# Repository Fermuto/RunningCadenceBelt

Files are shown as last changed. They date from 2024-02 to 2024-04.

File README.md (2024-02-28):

# RunningCadenceBelt

Running cadence is the number of steps a runner takes per minute while running, commonly measured in strides per minute (SPM). It is a useful measurement for runners as it can provide insight into efficiency, form, and stride length. An ideal cadence for most runners typically falls into the range of 170 to 180 SPM although this is dependent on height and pace.

Currently, there are already products on the market that can measure running cadence. For example, most “running watches” have cadence as an included measurement. However, it can be cumbersome for runners to constantly switch through display screens to monitor multiple data points at the same time such as pace, heart rate, distance, and cadence. Furthermore, unless a runner is running with their arm locked in front of them, continuous monitoring of cadence is impossible with a running watch. Other products take a different approach such as the foot-mounted ARION Footpod non-GPS 1.0 and Stryd. These products can track the cadence throughout the run in much the same way that a running watch would, but they can’t provide that information to the runner without the use of a watch or smartphone. In both the watch and foot-mounted solution, there is a lack of a product that provides easy, hands-free haptic feedback to the runner informing them when their cadence falls outside of the ideal cadence range.

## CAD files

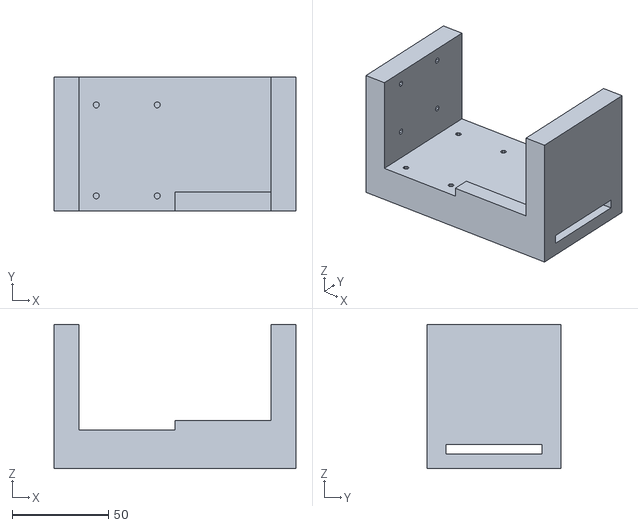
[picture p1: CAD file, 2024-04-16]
3D Print/Print.stl
126.0 x 70.0 x 75.0

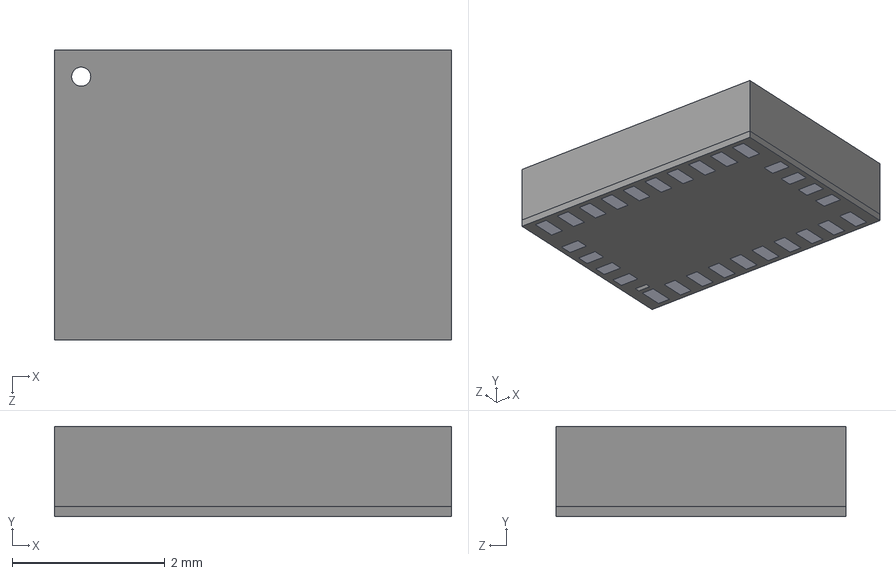
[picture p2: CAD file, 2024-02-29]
PCB/footprints/BNO085/BNO085.step
5.20 x 1.18 x 3.80 mm

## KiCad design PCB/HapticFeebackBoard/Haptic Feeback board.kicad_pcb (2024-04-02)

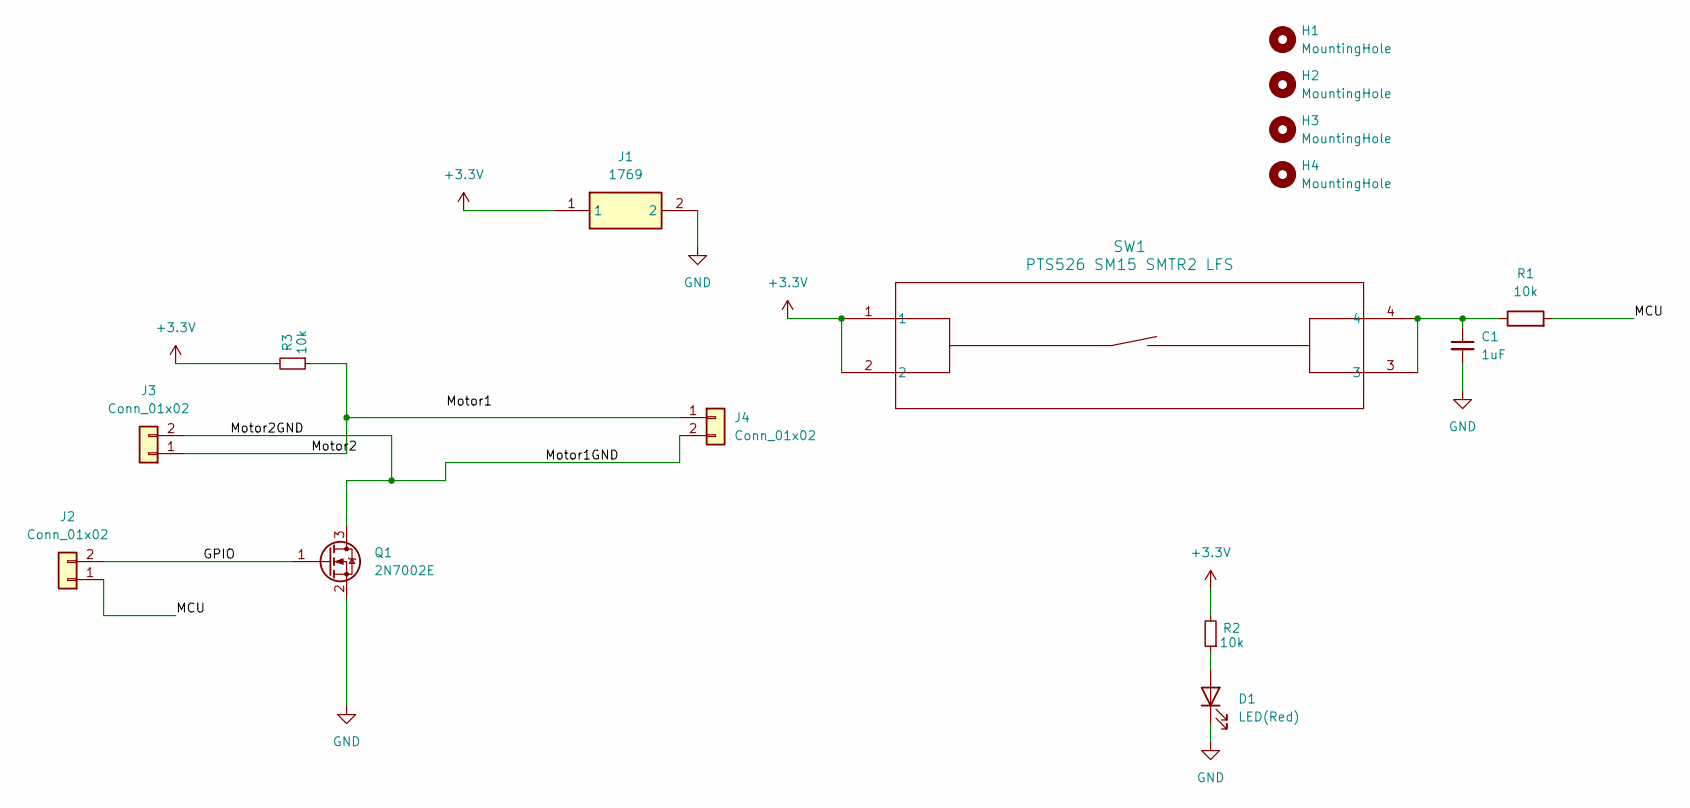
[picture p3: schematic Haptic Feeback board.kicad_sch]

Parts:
C1: 1uF; C_0805_2012Metric_Pad1.18x1.45mm_HandSolder
D1: LED(Red); LED_0603_1608Metric_Pad1.05x0.95mm_HandSolder
H1, H2, H3, H4: MountingHole; MountingHole_3.2mm_M3
J1: 1769; Mouser Part Number 485-1769
J2, J3, J4: Conn_01x02; Molex_KK-254_AE-6410-02A_1x02_P2.54mm_Vertical
Q1: 2N7002E; SOT-23-3
R1, R2, R3: 10k; R_0805_2012Metric_Pad1.20x1.40mm_HandSolder
SW1: PTS526 SM15 SMTR2 LFS; SON4_PTS526 SM15 SMTR2 LFS_CNK

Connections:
+3.3V: J1.1, R2.2, R3.2, SW1.1, SW1.2
/GPIO: J2.2, Q1.1 (G)
/MCU: J2.1, R1.2
/Motor1GND: J3.2, J4.2, Q1.3 (D)
/Motor2: J3.1, J4.1, R3.1
GND: C1.2, D1.1 (K), J1.2, Q1.2 (S)
unnamed: C1.1, R1.1, SW1.3, SW1.4
unnamed: D1.2 (A), R2.1

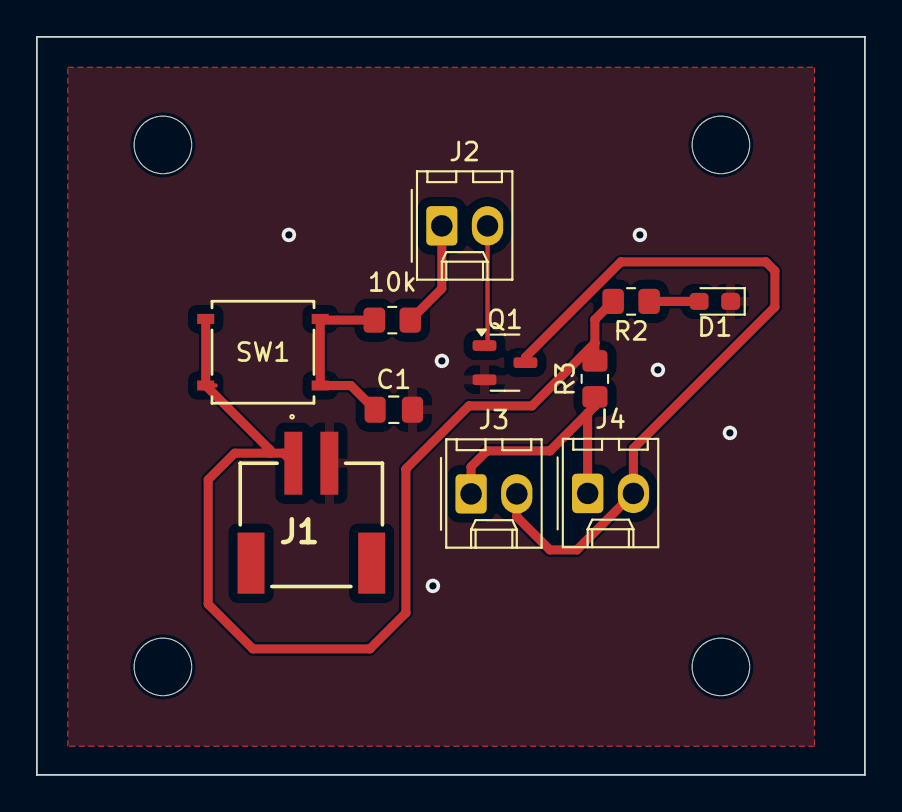
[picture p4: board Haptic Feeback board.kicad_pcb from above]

Board: 2 copper layers, 46.0 x 41.0 mm, 15 parts (0 on the bottom side), 8 nets.

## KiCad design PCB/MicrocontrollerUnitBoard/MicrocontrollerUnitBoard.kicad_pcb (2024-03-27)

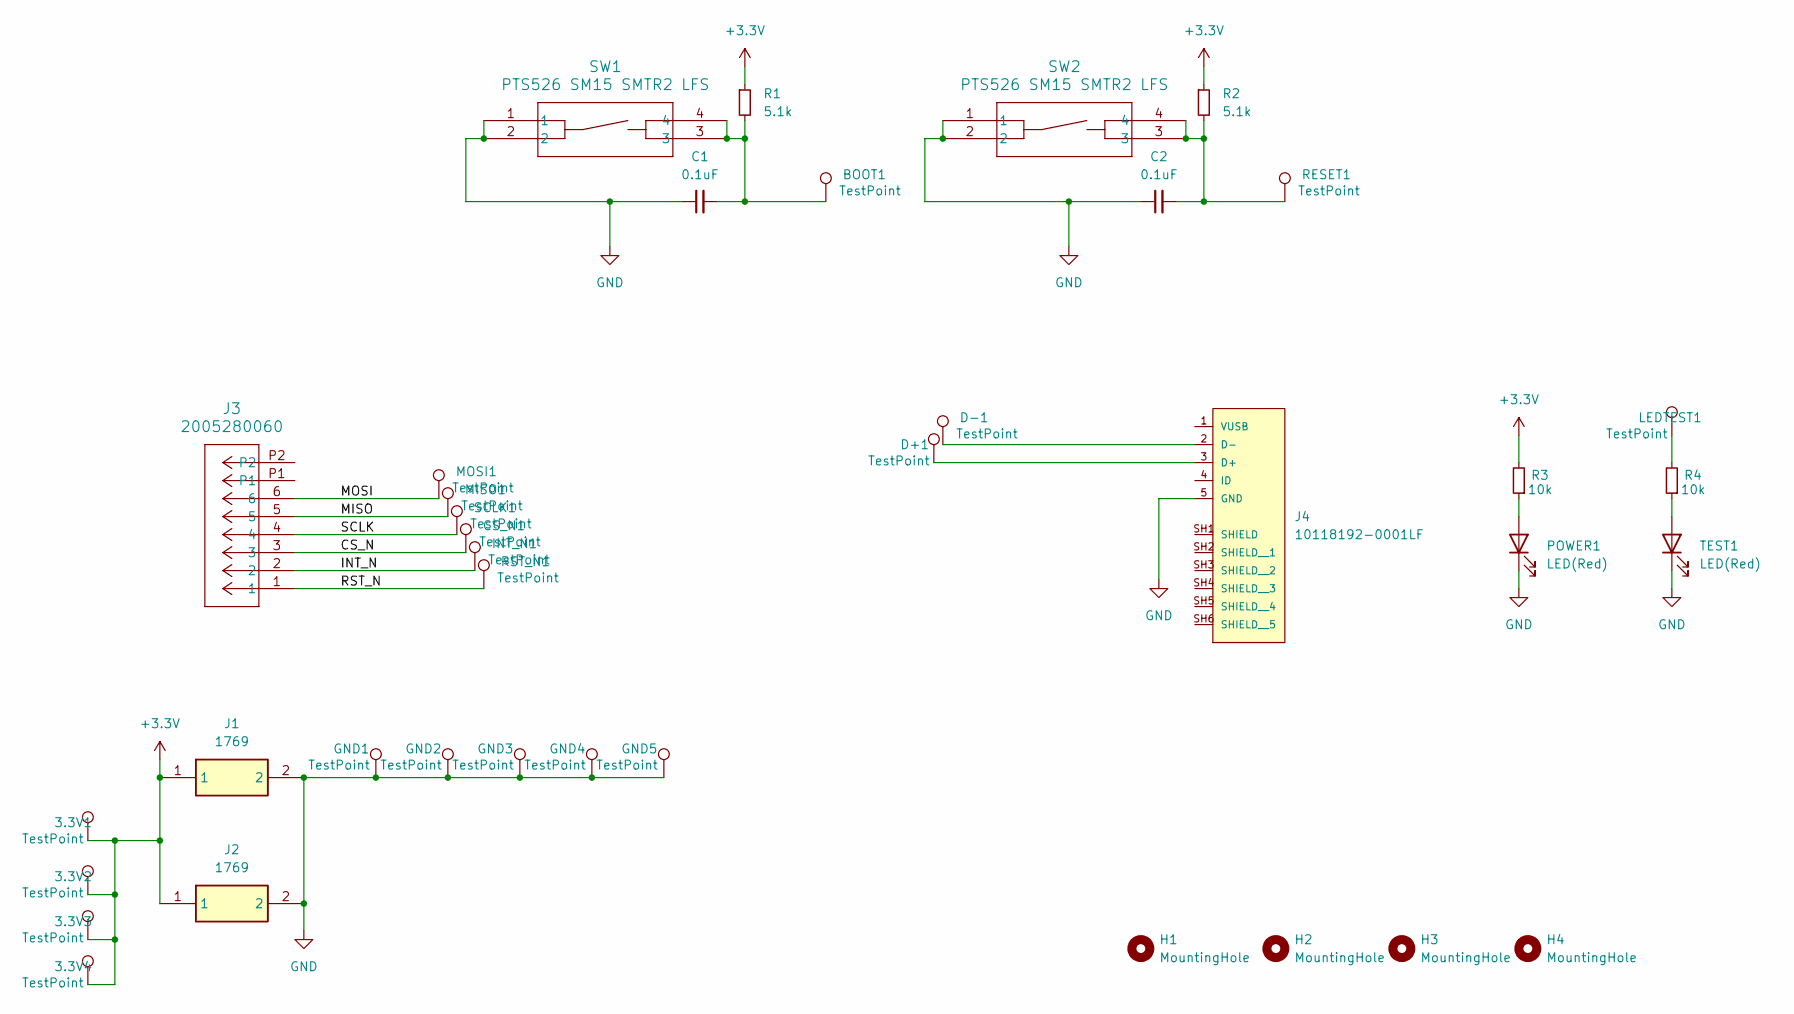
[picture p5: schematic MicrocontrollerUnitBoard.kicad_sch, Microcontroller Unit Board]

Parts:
3.3V1, 3.3V2, 3.3V3, 3.3V4: TestPoint; TestPoint_THTPad_D2.0mm_Drill1.0mm
BOOT1: TestPoint; TestPoint_THTPad_D2.0mm_Drill1.0mm
C1, C2: 0.1uF; C_0805_2012Metric_Pad1.18x1.45mm_HandSolder
CS_N1: TestPoint; TestPoint_THTPad_D2.0mm_Drill1.0mm
D+1: TestPoint; TestPoint_THTPad_D2.0mm_Drill1.0mm
D-1: TestPoint; TestPoint_THTPad_D2.0mm_Drill1.0mm
GND1, GND2, GND3, GND4, GND5: TestPoint; TestPoint_THTPad_D2.0mm_Drill1.0mm
H1, H2, H3, H4: MountingHole; MountingHole_3.2mm_M3
INT_N1: TestPoint; TestPoint_THTPad_D2.0mm_Drill1.0mm
J1, J2: 1769; Mouser Part Number 485-1769
J3: 2005280060; CON_2005280060_MOL
J4: 10118192-0001LF; AMPHENOL_10118192-0001LF; PARTREV B
LEDTEST1: TestPoint; TestPoint_THTPad_D2.0mm_Drill1.0mm
MISO1: TestPoint; TestPoint_THTPad_D2.0mm_Drill1.0mm
MOSI1: TestPoint; TestPoint_THTPad_D2.0mm_Drill1.0mm
POWER1: LED(Red); LED_0603_1608Metric_Pad1.05x0.95mm_HandSolder
R1, R2: 5.1k; R_0805_2012Metric_Pad1.20x1.40mm_HandSolder
R3, R4: 10k; R_0805_2012Metric_Pad1.20x1.40mm_HandSolder
RESET1: TestPoint; TestPoint_THTPad_D2.0mm_Drill1.0mm
RST_N1: TestPoint; TestPoint_THTPad_D2.0mm_Drill1.0mm
SCLK1: TestPoint; TestPoint_THTPad_D2.0mm_Drill1.0mm
SW1, SW2: PTS526 SM15 SMTR2 LFS; SON4_PTS526 SM15 SMTR2 LFS_CNK
TEST1: LED(Red); LED_0603_1608Metric_Pad1.05x0.95mm_HandSolder

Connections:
+3.3V: 3.3V1.1, 3.3V2.1, 3.3V3.1, 3.3V4.1, J1.1, J2.1, R1.1, R2.1, R3.2
/CS_N: CS_N1.1, J3.3
/INT_N: INT_N1.1, J3.2
/MISO: J3.5, MISO1.1
/MOSI: J3.6, MOSI1.1
/RST_N: J3.1, RST_N1.1
/SCLK: J3.4, SCLK1.1
GND: C1.1, C2.1, GND1.1, GND2.1, GND3.1, GND4.1, GND5.1, J1.2, J2.2, J4.5 (GND), POWER1.1 (K), SW1.1, SW1.2, SW2.1, SW2.2, TEST1.1 (K)
unnamed: BOOT1.1, C1.2, R1.2, SW1.3, SW1.4
unnamed: C2.2, R2.2, RESET1.1, SW2.3, SW2.4
unnamed: D+1.1, J4.3 (D+)
unnamed: D-1.1, J4.2 (D-)
unnamed: LEDTEST1.1, R4.2
unnamed: POWER1.2 (A), R3.1
unnamed: R4.1, TEST1.2 (A)

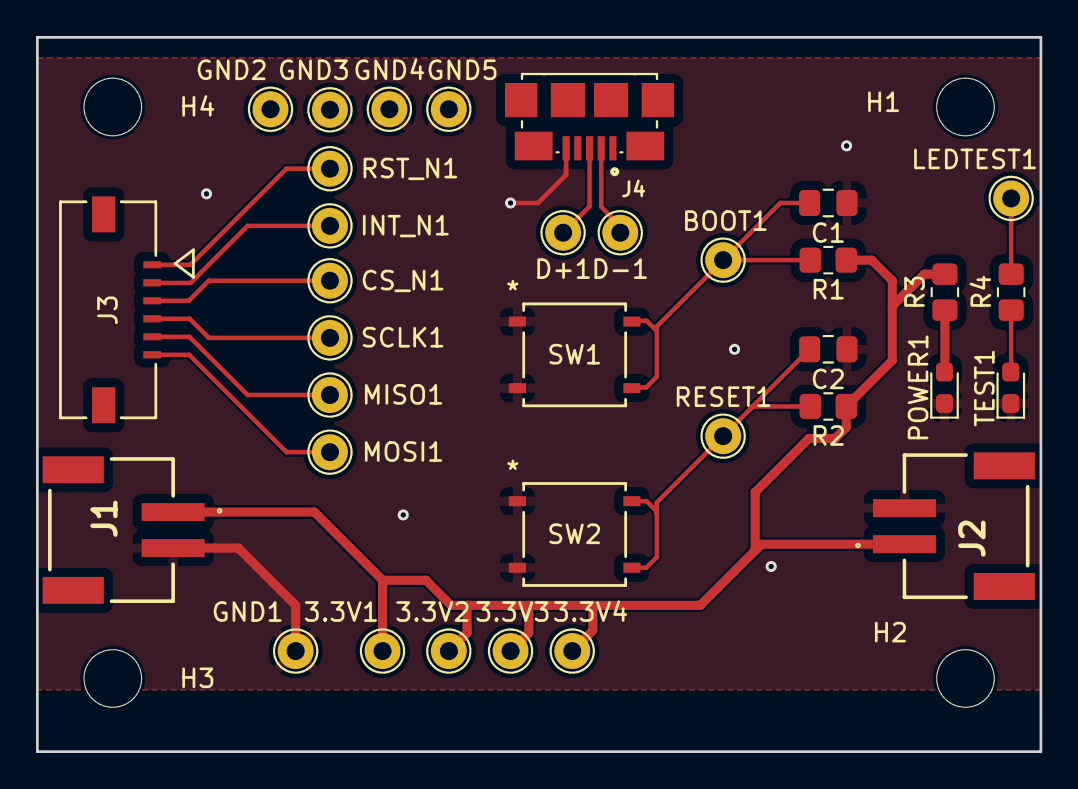
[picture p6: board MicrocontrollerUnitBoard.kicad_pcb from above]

Board: 2 copper layers, 55.8 x 39.7 mm, 38 parts (0 on the bottom side), 15 nets.

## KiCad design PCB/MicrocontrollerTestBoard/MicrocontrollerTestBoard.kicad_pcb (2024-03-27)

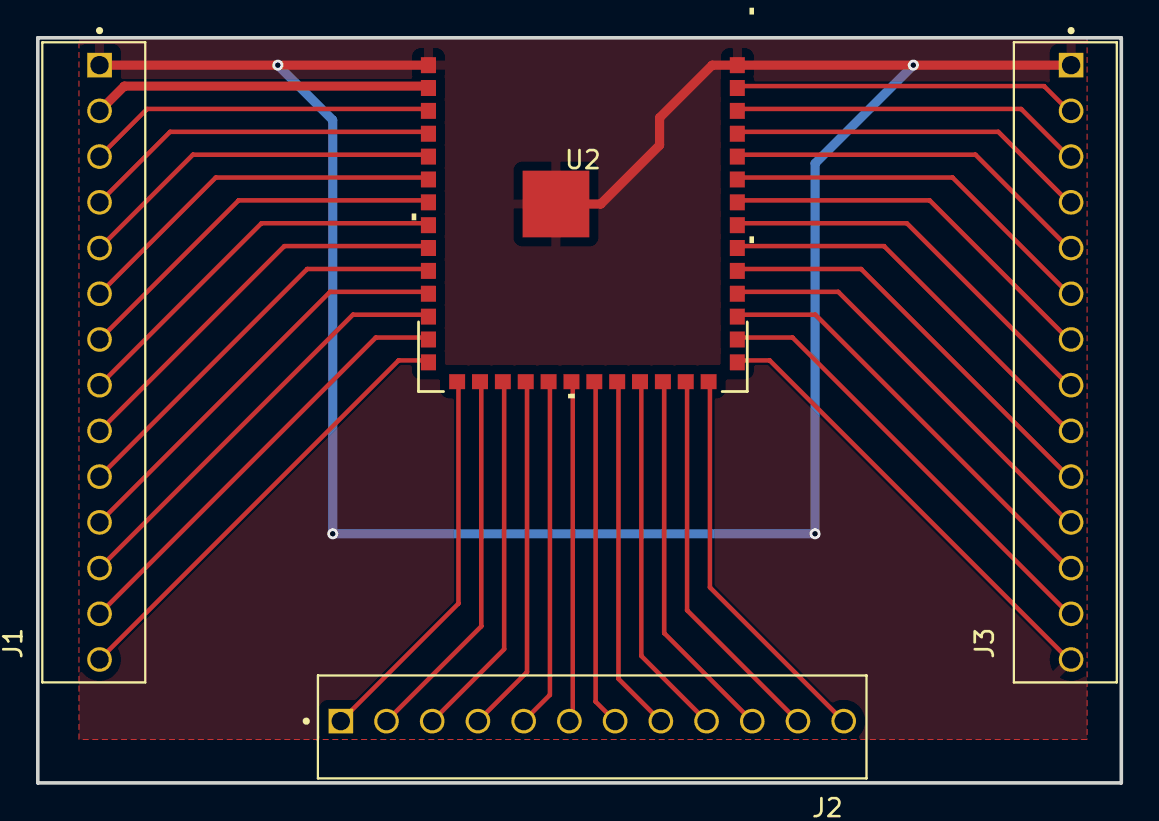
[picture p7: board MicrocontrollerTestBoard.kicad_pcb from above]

Board: 2 copper layers, 60.2 x 41.4 mm, 4 parts (0 on the bottom side), 38 nets.

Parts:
J1, J3: 1-640456-4; Connector Header Through Hole 14 position 0.100 (2.54mm)
J2: 1-640456-2; Connector Header Through Hole 12 position 0.100 (2.54mm)
U2: ESP32-S3-WROOM-1-N16; ESP32-S3-WROOM-1_EXP

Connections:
unnamed: J1.2, U2.2 (3V3)
unnamed: J1.3, U2.3 (EN)
unnamed: J1.1, J3.1, J3.14, U2.1 (GND), U2.40 (GND), U2.41 (EPAD)
unnamed: J3.13, U2.27 (IO0)
unnamed: J3.2, U2.38 (IO2)
unnamed: J2.1, U2.15 (IO3)
unnamed: J1.4, U2.4 (IO4)
unnamed: J1.5, U2.5 (IO5)
unnamed: J1.6, U2.6 (IO6)
unnamed: J1.7, U2.7 (IO7)
unnamed: J1.12, U2.12 (IO8)
unnamed: J2.3, U2.17 (IO9)
unnamed: J2.4, U2.18 (IO10)
unnamed: J2.5, U2.19 (IO11)
unnamed: J2.6, U2.20 (IO12)
unnamed: J2.7, U2.21 (IO13)
unnamed: J2.8, U2.22 (IO14)
unnamed: J1.8, U2.8 (IO15)
unnamed: J1.9, U2.9 (IO16)
unnamed: J1.10, U2.10 (IO17)
unnamed: J1.11, U2.11 (IO18)
unnamed: J1.13, U2.13 (IO19)
unnamed: J1.14, U2.14 (IO20)
unnamed: J2.9, U2.23 (IO21)
unnamed: J3.12, U2.28 (IO35_B)
unnamed: J3.11, U2.29 (IO36_B)
unnamed: J3.10, U2.30 (IO37_B)
unnamed: J3.9, U2.31 (IO38)
unnamed: J3.8, U2.32 (IO39)
unnamed: J3.7, U2.33 (IO40)
unnamed: J3.6, U2.34 (IO41)
unnamed: J3.5, U2.35 (IO42)
unnamed: J2.12, U2.26 (IO45)
unnamed: J2.2, U2.16 (IO46)
unnamed: J2.10, U2.24 (IO47)
unnamed: J2.11, U2.25 (IO48)
unnamed: J3.4, U2.36 (RXD0)
unnamed: J3.3, U2.37 (TXD0)

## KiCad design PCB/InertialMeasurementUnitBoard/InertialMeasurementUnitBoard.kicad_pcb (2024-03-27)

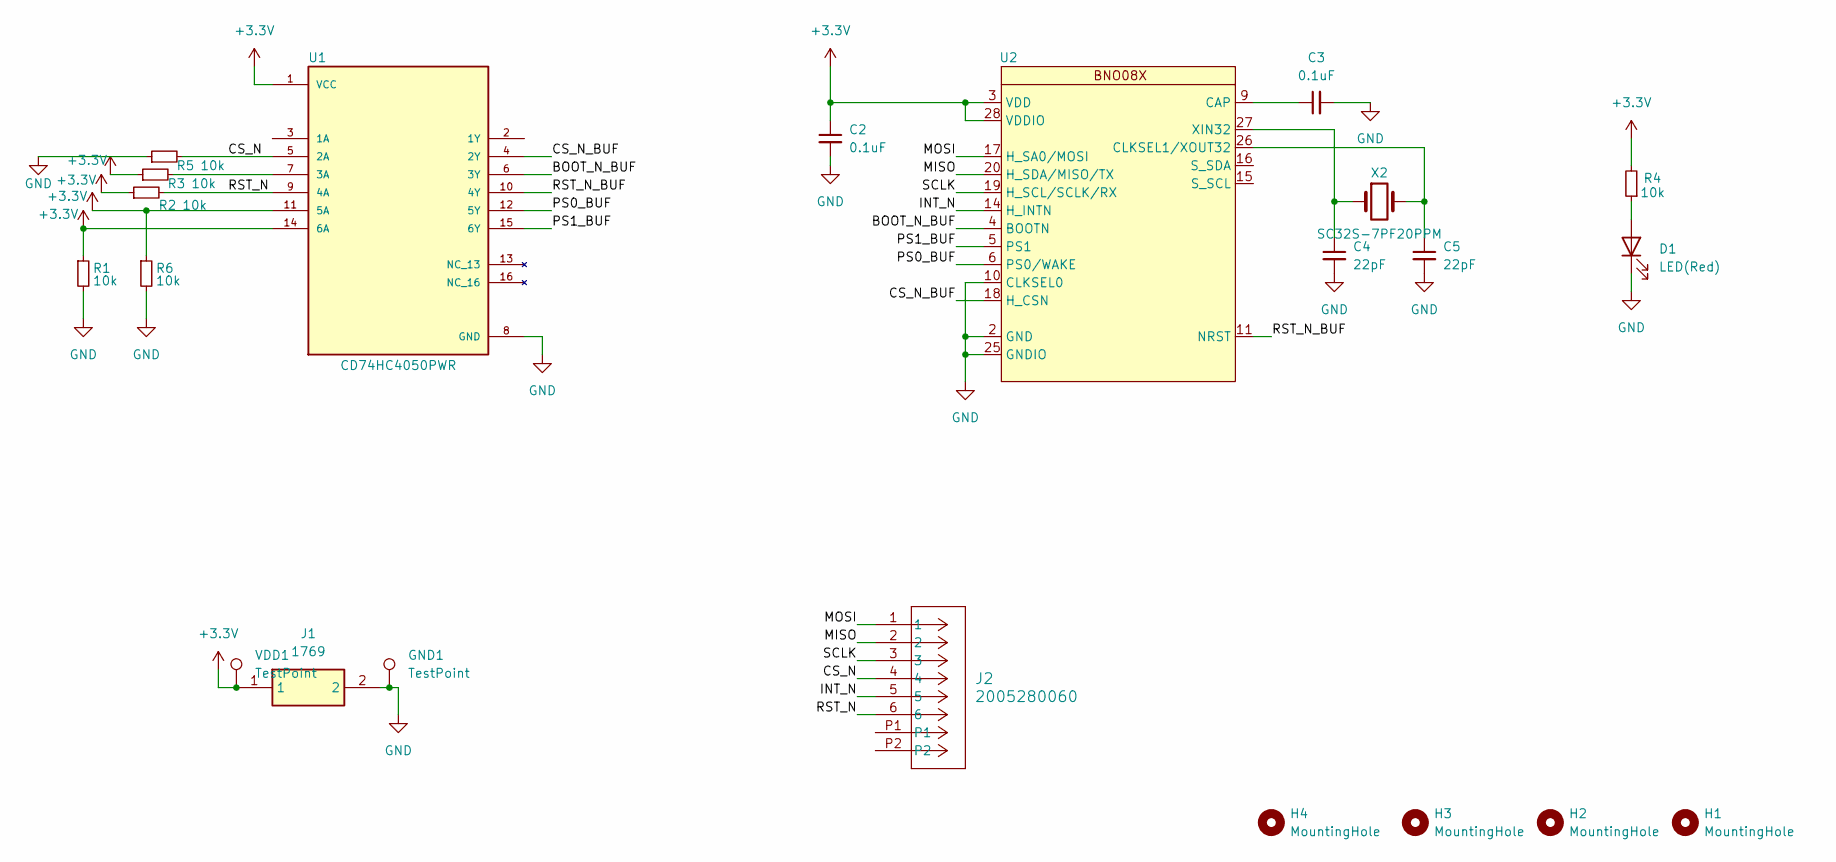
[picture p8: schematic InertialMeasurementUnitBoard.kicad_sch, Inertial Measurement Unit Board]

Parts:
C2, C3: 0.1uF; C_0805_2012Metric_Pad1.18x1.45mm_HandSolder
C4, C5: 22pF; C_0603_1608Metric_Pad1.08x0.95mm_HandSolder
D1: LED(Red); LED_0603_1608Metric_Pad1.05x0.95mm_HandSolder
GND1: TestPoint; TestPoint_THTPad_D2.0mm_Drill1.0mm
H1, H2, H3, H4: MountingHole; MountingHole_3.2mm_M3
J1: 1769; Mouser Part Number 485-1769
J2: 2005280060; CON_2005280060_MOL
R1, R2, R3, R4, R5, R6: 10k; R_0805_2012Metric_Pad1.20x1.40mm_HandSolder
U1: CD74HC4050PWR; SOP65P640X120-16N; PARTREV February 2005
U2: IC_BNO080
VDD1: TestPoint; TestPoint_THTPad_D2.0mm_Drill1.0mm
X2: SC32S-7PF20PPM; XTAL_SC32S-7PF20PPM_EPS

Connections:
+3.3V: C2.1, J1.1, R1.1, R2.1, R3.1, R4.2, R6.1, U1.1 (VCC), U1.11 (5A), U1.14 (6A), U2.3 (VDD), U2.28 (VDDIO), VDD1.1
/BOOT_N_BUF: U1.6 (3Y), U2.4 (BOOTN)
/CS_N: J2.4, R5.2, U1.5 (2A)
/CS_N_BUF: U1.4 (2Y), U2.18 (H_CSN)
/INT_N: J2.5, U2.14 (H_INTN)
/MISO: J2.2, U2.20 (H_SDA/MISO/TX)
/MOSI: J2.1, U2.17 (H_SA0/MOSI)
/PS0_BUF: U1.12 (5Y), U2.6 (PS0/WAKE)
/PS1_BUF: U1.15 (6Y), U2.5 (PS1)
/RST_N: J2.6, R2.2, U1.9 (4A)
/RST_N_BUF: U1.10 (4Y), U2.11 (NRST)
/SCLK: J2.3, U2.19 (H_SCL/SCLK/RX)
GND: C2.2, C3.2, C4.2, C5.2, D1.1 (K), GND1.1, J1.2, R1.2, R5.1, R6.2, U1.8 (GND), U2.2 (GND), U2.10 (CLKSEL0), U2.25 (GNDIO)
unnamed: D1.2 (A), R4.1
unnamed: R3.2, U1.7 (3A)
unnamed: C3.1, U2.9 (CAP)
unnamed: C5.1, U2.26 (CLKSEL1/XOUT32), X2.2
unnamed: C4.1, U2.27 (XIN32), X2.1

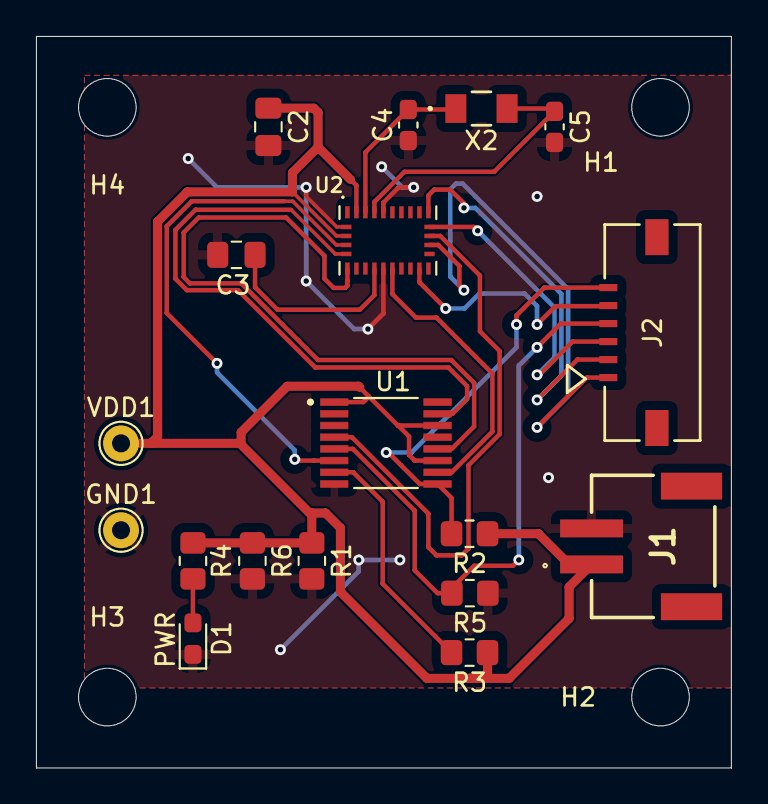
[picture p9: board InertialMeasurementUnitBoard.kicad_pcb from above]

Board: 2 copper layers, 38.6 x 40.6 mm, 22 parts (0 on the bottom side), 18 nets.

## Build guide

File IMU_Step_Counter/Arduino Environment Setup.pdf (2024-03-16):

### How to Set Up the Arduino Environment for the ESP32-S3

1. Open the Arduino IDE
a. Download the software (https://www.arduino.cc/en/software) if you do not have it already.
2. Install the ESP32 Boards to the Board Manager
a. Go to File → Preferences
b. Paste the following link in the “Additional Boards Manager URLs” textspace: https://dl.espressif.com/dl/package_esp32_index.json
c. Select OK
d. Go to Tools → Board → Board Manager
e. Type ESP32
f. Install the ESP32 Library
3. Set your Board to “ESP32S3 Dev Module”
a. Go to Tools → Board → “ESP32S3 Dev Module”
4. Install the BNO08x Libraries
a. Go to Sketch → Include Library → Manage Libraries
b. Search for “bno08x”
c. Install the “Adafruit BNO08x” Library

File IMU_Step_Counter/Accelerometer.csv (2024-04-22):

time | seconds_elapsed | z | y | x
1713313080571836400 | 0.04183642578125 | 0 | 0 | 0
1713313080581371400 | 0.051371337890625 | 0.010332107543945312 | -0.013223409652709961 | 0.14880523085594177
1713313080590906400 | 0.06090625 | 0.05424785614013672 | -0.040418386459350586 | 0.26986247301101685
1713313080600441300 | 0.07044140625 | 0.07436847686767578 | -0.11118388175964355 | 0.3659246563911438
1713313080609976300 | 0.079976318359375 | 0.04424858093261719 | -0.25551629066467285 | 0.3970373272895813
1713313080619511300 | 0.08951123046875 | 0.1860818862915039 | -0.38645505905151367 | 0.22556841373443604
1713313080629046300 | 0.09904638671875 | 0.43485069274902344 | -0.44400978088378906 | -0.04939553141593933
1713313080638581200 | 0.108581298828125 | 0.7503204345703125 | -0.43407678604125977 | -0.33442550897598267
1713313080648116200 | 0.1181162109375 | 1.0909156799316406 | -0.3673543930053711 | -0.6084715127944946
1713313080657651200 | 0.127651123046875 | 1.3364982604980469 | -0.23758983612060547 | -0.8342683911323547
1713313080667186200 | 0.137186279296875 | 1.4960613250732422 | -0.1870417594909668 | -0.8000631928443909
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

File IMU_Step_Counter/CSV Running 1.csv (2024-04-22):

seconds_elapsed | accelerometer_z | accelerometer_y | accelerometer_x | pedometer_steps | totalAcceleration_z | totalAcceleration_y | totalAcceleration_x | accelerometerUncalibrated_z | accelerometerUncalibrated_y | accelerometerUncalibrated_x
0 | 0.114875657 | -0.178686687 | 0.193971796 |  | 9.439445877 | 3.227917766571045 | 0.4778466820716858 | 9.392825762430826 | 3.309672554334005 | 0.4103690832853317
0.1 | 0.948329926 | -0.305089998 | -0.303076813 |  | 10.91148897 | 2.6897501945495605 | -0.112027602 | 10.911488966508346 | 2.6897501945495605 | -0.112027602
0.2 | -0.951273918 | 0.121706247 | 0.476246533 |  | 8.975597382 | 3.2705099821090697 | 0.7018148899078369 | 8.975597381591797 | 3.2705099821090697 | 0.7018148899078369
0.3 | -0.923491335 | 0.02732594 | 0.563940725 |  | 8.73206234 | 3.058897473595359 | 0.7220886160026897 | 8.732062339782715 | 3.058897473595359 | 0.7220886160026897
0.4 | 0.452748299 | 0.484262336 | 1.905794221 |  | 10.30337472 | 3.5484363555908205 | 2.351187478750944 | 10.30337471961975 | 3.5484363555908205 | 2.351187478750944
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

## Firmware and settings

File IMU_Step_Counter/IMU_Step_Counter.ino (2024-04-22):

#include <Arduino.h>
#include <Adafruit_BNO08x.h>
#include <Time.h>

// SPI mode:
#define ESP32_MOSI GPIO_NUM_13
#define ESP32_MISO GPIO_NUM_12
#define ESP32_SCLK GPIO_NUM_14
#define ESP32_CS GPIO_NUM_15

#define BNO08X_CS GPIO_NUM_10
#define BNO08X_INT GPIO_NUM_9
#define BNO08X_RESET GPIO_NUM_5

// #define Test5 GPIO_NUM_5

#define num_sam 150

Adafruit_BNO08x bno08x(BNO08X_RESET);
sh2_SensorValue_t sensorValue;

unsigned long now;
unsigned long lastsig = 0;

int steps = 0;
int cadence;
int target = 180;

float threshold = 0;  // TODO: Find this number (Testing/Debugging)
int isStep = 0;
float accel[num_sam];
float ax[num_sam];
float ay[num_sam];
float az[num_sam];

// Build the Low-pass Filter (Outlined for 2nd Order)
float b[] = {0.007777, 0.01555399, 0.007777};       // Filter coeffs. can be obtained using the
float a[] = {-1.73550016, 0.76660814};              // Python code I provided in the directory

// Holds previous values for filter use
float x[3];
float y[3];

void setup() {
  pinMode(LED_BUILTIN, OUTPUT);
  pinMode(GPIO_NUM_4, OUTPUT);
  Serial.begin(115200);
  while (!Serial) delay(10);

  Serial.println("ax,ay,az,Net_Acceleration");
  bno08x.begin_SPI(BNO08X_CS, BNO08X_INT);
  if (bno08x.begin_SPI(BNO08X_CS, BNO08X_INT)) {
    Serial.println("Failed to find BNO08x chip");
    while (1);
  }
  Serial.println("BNO08x Found!");
}

void loop() { 
  // Serial.print('*');
  //digitalWrite(LED_BUILTIN, HIGH);
  Serial.print("Bruh");
//  for (int i = 0; i < num_sam; i++){
//    ax[i] = sensorValue.un.accelerometer.x;    // TODO: Fix this
//    Serial.print(ax[i]);
//    Serial.print("\t");
//    delay(1);
//    ay[i] = sensorValue.un.accelerometer.y;
//    Serial.print(ay[i]);
//    Serial.print("\t");
//    delay(1);
//    az[i] = sensorValue.un.accelerometer.z;
//    delay(1);
//    accel[i] = sqrt( (ax[i]*ax[i]) + (ay[i]*ay[i]) + (az[i]*az[i]) );
//    Serial.println(accel[i]);
//    delay(1);
//  }
//
//  //digitalWrite(LED_BUILTIN, LOW);
//  //--------------------------------Apply the Filter--------------------------------
//  for (int i = 0; i < num_sam; i++){
//    x[0] = accel[i];
//    y[0] = b[0]*x[0] + b[1]*x[1] + b[2]*x[2] - a[1]*y[1] - a[2]*y[2];
//
//    x[2] = x[1];
//    x[1] = x[0];
//    y[2] = y[1];
//    y[1] = y[0];
//
//    accel[i] = y[0];
//  //--------------------------------------------------------------------------------
//  
//    delay(500);        // TODO: Will adjust this during debugging
//
//    if ((accel[i] > threshold) && (isStep == 0)){
//      steps = steps + 1;
//      isStep = 1;
//    }
//    if ((accel[i] < threshold) && (isStep == 1)){
//      isStep = 0;
//    }
//  }
//
//  // TODO: Fix Crude Algorithm, make it work
//
//  now = millis();
//  cadence = (steps*60000)/(now);
//  //Serial.println(cadence);
//  
//  if ((now - lastsig) > 10000){
//    if (cadence > (target+5)){
//        // digitalWrite(pin, HIGH)
//        delay(1000);
//        // digitalWrite(pin, LOW)
//    }
//    if (cadence < (target-5)){
//        // digitalWrite(pin, HIGH)
//        delay(500);
//        // digitalWrite(pin, LOW)
//        delay(250);
//        // digitalWrite(pin, HIGH)
//        delay(500);
//        // digitalWrite(pin, LOW)
//    }
//    lastsig = now;
//  }
  
}

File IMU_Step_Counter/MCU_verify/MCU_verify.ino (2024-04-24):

void setup() {
  // put your setup code here, to run once:
  pinMode(LED_BUILTIN, OUTPUT);
  pinMode(GPIO_NUM_4, OUTPUT);
  Serial.begin(115200);
  delay(1000);
}

void loop() {
  // put your main code here, to run repeatedly:
  digitalWrite(LED_BUILTIN, HIGH);
  digitalWrite(GPIO_NUM_4, HIGH); 
  delay(100);
  Serial.print("Bruh");
}

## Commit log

2024-02-29 Add BNO086 footprint/symbol, add ESP32-S3 symbol
    ESP32 symbol redundant
    [BNO085.step]
2024-02-29 Create IMU Board, MCU Board projects
    [InertialMeasurementUnitBoard.kicad_pcb, InertialMeasurementUnitBoard.kicad_sch, MicrocontrollerUnitBoard.kicad_pcb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]
2024-02-29 Reorganize into PCB folder
    [BNO085.step, InertialMeasurementUnitBoard.kicad_pcb, InertialMeasurementUnitBoard.kicad_sch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]
2024-02-29 Add CD74HC4050PWR symbol, footprint
2024-02-29 Move BNO08X footprint
2024-02-29 Initial work on IMU board
    Some configuration work done; added power LED
    [InertialMeasurementUnitBoard.kicad_sch]
2024-02-29 Add PTS526 SM15 SMTR2 LFS footprint/symbol
2024-02-29 Finish IMU schematic
    [InertialMeasurementUnitBoard.kicad_pcb, InertialMeasurementUnitBoard.kicad_sch]
2024-02-29 Add SC32S-7PF20PPM footprint/symbol
2024-02-29 Add 2-pin JST, 6-7-9-pin FFC conn footprint/symbol
2024-02-29 2/29 IMU Board
    Added connectors to schematic, started layout
    [InertialMeasurementUnitBoard.kicad_pcb, InertialMeasurementUnitBoard.kicad_sch]
2024-02-29 Started Haptic Feedback Board Schematic
    [Haptic Feeback board.kicad_pcb, Haptic Feeback board.kicad_sch]
2024-03-01 Updated Haptic Feedback Board
    Should be close to final schematic
    [Haptic Feeback board.kicad_pcb, Haptic Feeback board.kicad_sch]
2024-03-01 Initial completion of Inertial Measurement Unit Board
    Add test points for BMS outputs, complete layout.
    [InertialMeasurementUnitBoard.kicad_pcb, InertialMeasurementUnitBoard.kicad_sch]
2024-03-01 Support on haptic feedback board
    Added schematic details, imported PCBWay DRC
    [Haptic Feeback board.kicad_pcb, Haptic Feeback board.kicad_sch]
2024-03-01 Small edits to IMU board layout
    Tidying up of silkscreen, traces, fab, etc.
    [InertialMeasurementUnitBoard.kicad_pcb]
2024-03-01 Update IMU board schematic details
    [InertialMeasurementUnitBoard.kicad_sch]
2024-03-01 3/1 MCU Board progress upload for board review
    [MicrocontrollerUnitBoard.kicad_sch]
2024-03-03 Create microcontroller test board
    [MicrocontrollerTestBoard.kicad_pcb, MicrocontrollerTestBoard.kicad_sch]
2024-03-03 Finished Haptic Feedback Board
    [Haptic Feeback board.kicad_pcb]
2024-03-03 Revert "Attempting to push"
    This reverts commit dba7137e2b6d79e6a799e918ac76b279f377e3a9, reversing
    changes made to e00eed14296bda41403d05f06b408ec44583351d.
    [Haptic Feeback board.kicad_pcb, Haptic Feeback board.kicad_sch]
2024-03-03 Revert "Finished Haptic Feedback Board"
    This reverts commit e00eed14296bda41403d05f06b408ec44583351d.
    [Haptic Feeback board.kicad_pcb]
2024-03-03 Pushing Haptic Feedback
    [Haptic Feeback board.kicad_pcb]
2024-03-03 recovery attempt
    [MicrocontrollerUnitBoard.kicad_sch]
2024-03-03 Recovery attempt 2
    [Haptic Feeback board.kicad_pcb, Haptic Feeback board.kicad_sch, InertialMeasurementUnitBoard.kicad_pcb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]
2024-03-03 Update IMU Board thicker power trace
    [InertialMeasurementUnitBoard.kicad_pcb]
2024-03-03 Create MicrocontrollerTestBoard
    [MicrocontrollerTestBoard.kicad_pcb, MicrocontrollerTestBoard.kicad_sch]
2024-03-03 Updating Haptic Feedback Board
    [Haptic Feeback board.kicad_pcb, Haptic Feeback board.kicad_sch]
2024-03-03 Update trace widths IMU
    [InertialMeasurementUnitBoard.kicad_pcb]
2024-03-03 Edits to Haptic Feedback
    [Haptic Feeback board.kicad_pcb]
2024-03-04 Generated Gerber Files
    [Haptic Feeback board-B_Cu.gbr, Haptic Feeback board-B_Mask.gbr, Haptic Feeback board-B_Paste.gbr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]
2024-03-04 Minor copper pour adjustments
    [Haptic Feeback board.kicad_pcb]
2024-03-04 Further minor edits, added power LED
    [Haptic Feeback board.kicad_pcb, Haptic Feeback board.kicad_sch]
2024-03-04 Small updates on IMU, initial finish of MCU
    [InertialMeasurementUnitBoard.kicad_pcb, MicrocontrollerUnitBoard.kicad_pcb, MicrocontrollerUnitBoard.kicad_sch]
2024-03-04 Add male header, ESP32-S3-WROOM-1 symbols/footprints
2024-03-04 Finish MCU Test board
    [MicrocontrollerTestBoard.kicad_pcb, MicrocontrollerTestBoard.kicad_sch, MicrocontrollerUnitBoard.kicad_pcb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]
2024-03-04 Create MCU Test gerbers, drill, passes audit
    [MicrocontrollerTestBoard-B_Courtyard.gbr, MicrocontrollerTestBoard-B_Cu.gbl, MicrocontrollerTestBoard-B_Mask.gbs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]
2024-03-04 Final pass for 1st round order, generate gerbers for all, all pass audit
    [Haptic Feeback board-B_Courtyard.gbr, Haptic Feeback board-B_Cu.gbl, Haptic Feeback board-B_Cu.gbr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]
2024-03-16 Adding IMU Example Code + Environment Setup Insturctions
2024-03-22 Added Crude Step-Count Algorithm, and a Python Code which builds Low-Pass Filters
2024-03-27 Upload of zips used in 1st round pcb order
    [Haptic Feeback board-B_Cu.gbl, Haptic Feeback board-B_Mask.gbs, Haptic Feeback board-B_Paste.gbp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]
2024-04-02 Updated Haptic Feedback Board
    Changed motor to be connected to the drain rather than source
    [Haptic Feeback board-B_Courtyard.gbr, Haptic Feeback board-B_Cu.gbl, Haptic Feeback board-B_Mask.gbs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]
2024-04-02 updating ESP32 and BNO08x code
2024-04-03 Making minor improvements/fixes to code
    [IMU_Step_Counter.ino]
2024-04-16 Added 3D print file
    Added 3D print file. The print may be too heavy and not have enough space.
    [Print.stl]
2024-04-20 Desktop algorithm upload
    Algorithm verification, testing and tweaking before porting
    [Accelerometer.csv, CSV Running 1.csv]
2024-04-22 arduino upload
